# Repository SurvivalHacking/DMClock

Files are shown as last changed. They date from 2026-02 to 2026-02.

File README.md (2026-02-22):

# DMClock



IMG_5133_(00-00-00-00)

Background

## 📘 Descrizione / Description

Ispirato ai celebri display delle copertine dei singoli dei Depeche Mode, questo oggetto iconico diventa un vero orologio funzionante.
Segna ora e data, ma può anche rappresentare le annate storiche, proprio come nell’immaginario della band.
Un pezzo unico per veri fan.

Inspired by the famous displays on Depeche Mode's single covers, this iconic object becomes a real working clock.
It shows the time and date, but can also represent historical years, just like in the band's imagery.
A unique piece for true fans.

* Difficoltà/difficulties: Difficile / Hard
* Costo/cost: 30€
* Tempo / Time: 5 ore / 5 ours
* Attrezzature extra / extra devices: Stampante 3D / 3D printer

---
## 🎛️ Materiali / BOM

* Display C.C. 5161AS: https://s.click.aliexpress.com/e/_c3zw6A2p
* HT16K33 BackPack: https://s.click.aliexpress.com/e/_c2Q1blNZ
* ESP32C3: https://s.click.aliexpress.com/e/_DDST7Bj
* Button 6x6x12: https://s.click.aliexpress.com/e/_c4CBgRJJ
* Cavo 10 poli smaltato / 10 wire cable: https://s.click.aliexpress.com/e/_c3IRqse1
* PLA galaxy black: https://amzn.to/4rr7kVZ
* PLA gray glitter: https://amzn.to/4o0EEkQ

---

## 🎛️ Schema pratico di assemblaggio

Schema Pratico - Schematic

---
# 📝 Programmazione via WEB / WEB Programming

https://davidegatti.altervista.org/installaEsp32.php?progetto=DMClock 

---
## 🧾 Licenza

Questo progetto è distribuito con licenza
**Creative Commons – Attribuzione – Non Commerciale 4.0 Internazionale (CC BY-NC 4.0)**.

Puoi condividerlo e modificarlo liberamente, **citando l’autore**
(Davide Gatti / [survivalhacking](https://github.com/survivalhacking)) e **senza scopi commerciali**.

🔗 [https://creativecommons.org/licenses/by-nc/4.0/](https://creativecommons.org/licenses/by-nc/4.0/)

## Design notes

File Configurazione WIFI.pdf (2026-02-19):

# DM CLOCK

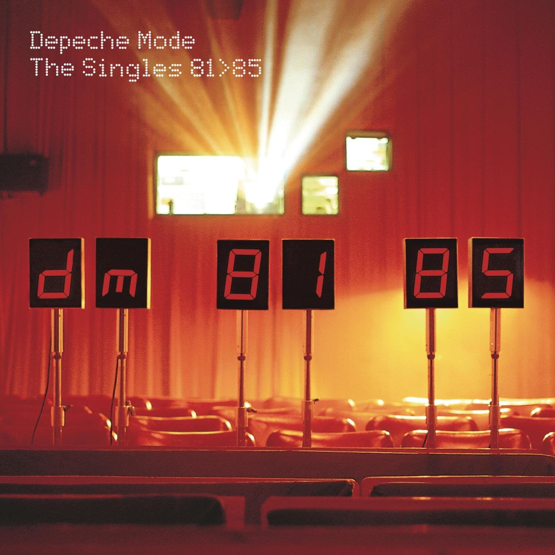
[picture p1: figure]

### Configurazione DM Clock

Questo orologio, prende l’ora da internet ed è quindi necessario collegarlo alla rete WIFI.

1) Alla prima accensione l’orologio mostra la scri=a WIFI che fa capire che è necessario collegarlo alla rete per proseguire.
2) UBlizzando un qualsiasi telefonino, cercare nella rete WIFI il disposiBvo DM-CLOCK e collegarsi ad esso
3) Se state usando un iPad o un iPhone, automaBcamente apparirà la schermata per la configurazione, diversamente sui disposiBvi Android sarà necessario collegarsi manualmente mediante un browser digitando il seguente indirizzo 192.168.4.1 oppure leggendo il seguente QR-CODE.

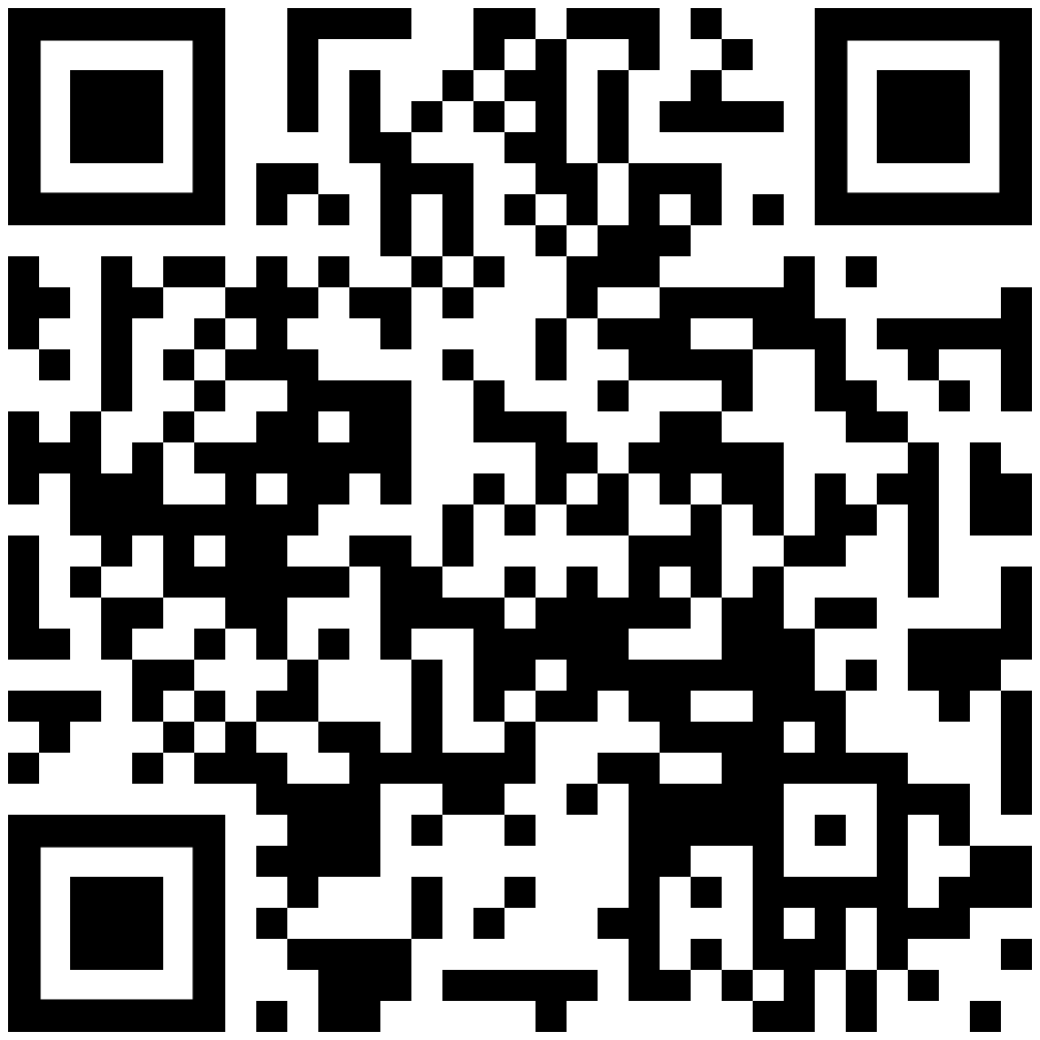
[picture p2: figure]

4) Una volta aperta la pagina di configurazione premere su ‘configure WiFi’

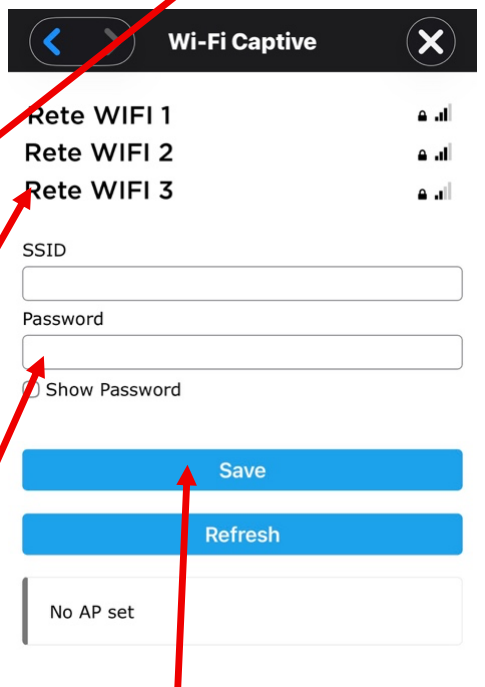
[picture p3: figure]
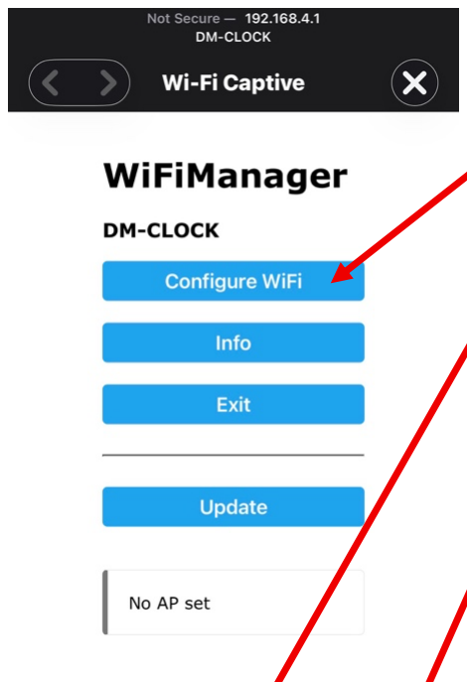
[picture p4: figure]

5) Selezionare la vostra rete WiFi e la password e premere ‘Save’
6) Se avete inserito le credenziali corre=amente, l’orologio si conne=erà automaBcamente e vi mostrerà l’indirizzo IP al quale è possibile raggiungerlo per eventuali configurazioni aggiunBve che sono opzionali, per cui se non necessario, saltare la parte di configurazione avanzata.

CONFIGURAZIONE AVANZATA

7) L’orologio da adesso in poi all’avvio mostrerà la scri=a “CONN” che significa che si sta conne=endo alla rete e a seguire vi mostrerà l’indirizzo IP assegnato. La visualizzazione avverrà in più passaggi IP= e poi 4 numeri in sequenza che una volta uniB comporranno l’indirizzo IP completo. Per esempio
IP=
192.
168.
1.
98.

Compongono l’indirizzo IP 192.168.1.98. Che se digitato sul proprio browser vi darà l’accesso alla pagina di configurazione estesa.

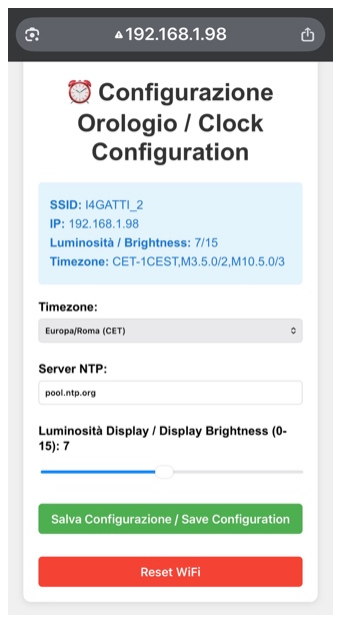
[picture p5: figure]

8) Da qui sarò possibile cambiare il Timezone, il server NTP, la luminosità ed eventualmente rese=are le impostazioni del WIFI che si possono comunque rese=are anche usando i due pulsanB presenB sull’orologio.

ISTRUZIONI OROLOGIO DM-CLOCK

L’orologio normalmente mostra l’ora che viene sincronizzata da internet e si regola automaBcamente anche l’ora legale.
Per interagire ci sono 2 pulsanB che consentono l’esecuzione di alcune impostazioni.

Pulsante di sinistra
Premendo il pulsante una prima volta, verrà mostrata la data per 5 secondi.
Premendo nuovamente il pulsante di sinistra viene mostrata la scri=a DM 81 85
Premendo nuovamente il pulsante di sinistra viene mostrata la scri=a 86 89 per 10 secondi Premendo nuovamente il pulsante di sinistra viene mostrata la scri=a 01 17 per 10 secondi
Premendo nuovamente il pulsante di sinistra viene mostrata la scri=a 01 24 per 10 secondi

Pulsante di destra
Premendo il pulsante si regola la luminosità. Ad ogni pressione si incrementa la luminosità che va da 0 a 15

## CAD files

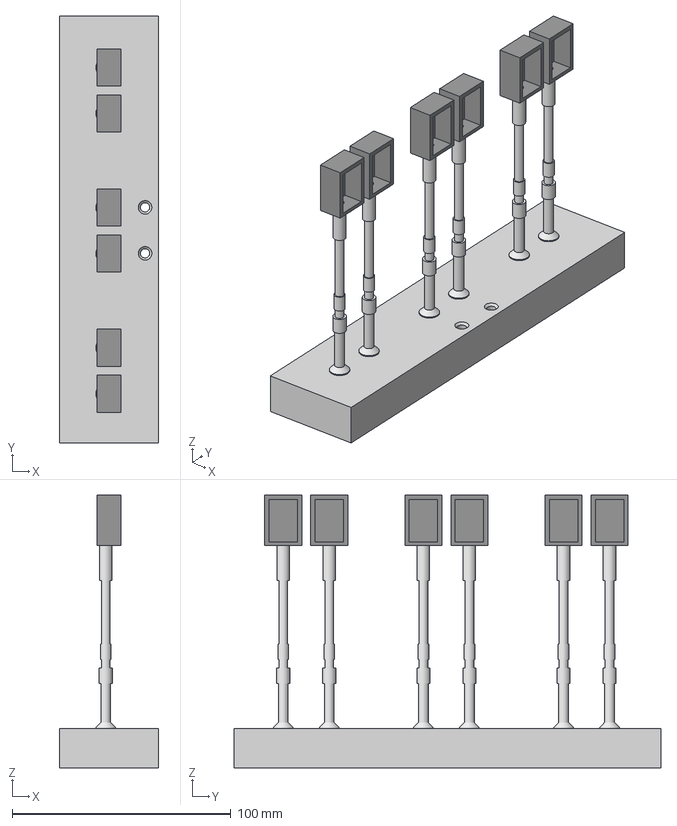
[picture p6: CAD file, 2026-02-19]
3D/DM Clock FULL.3mf
45.0 x 195.0 x 124.5 mm
Asta (1) (1)
Asta (2) (1) (1)
Asta (2) (1)
Asta (4) (1) (1)
Asta (4) (1)
Asta (6) (1)
BASE (1)
DISPLAY (1) (1)
DISPLAY (2) (1)
DISPLAY (3) (1)
DISPLAY (4) (1)
DISPLAY (5) (1)
DISPLAY (6)

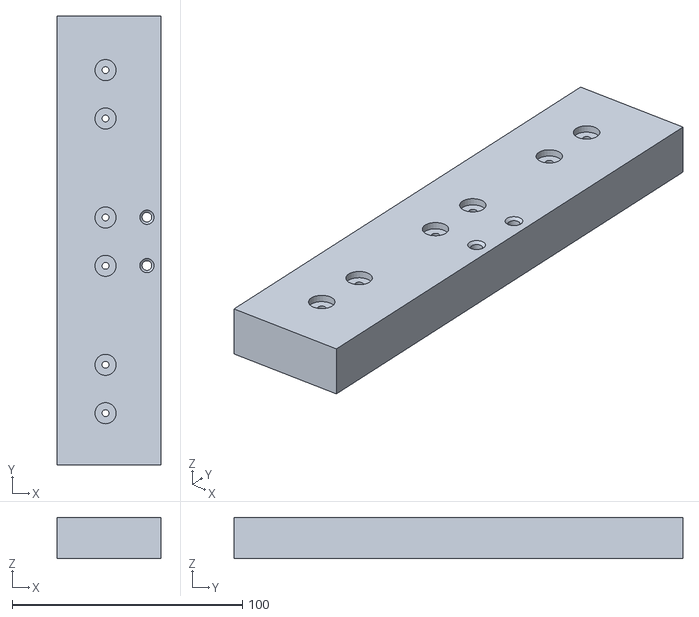
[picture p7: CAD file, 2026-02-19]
3D/BASE.stl
45.0 x 195.0 x 18.0

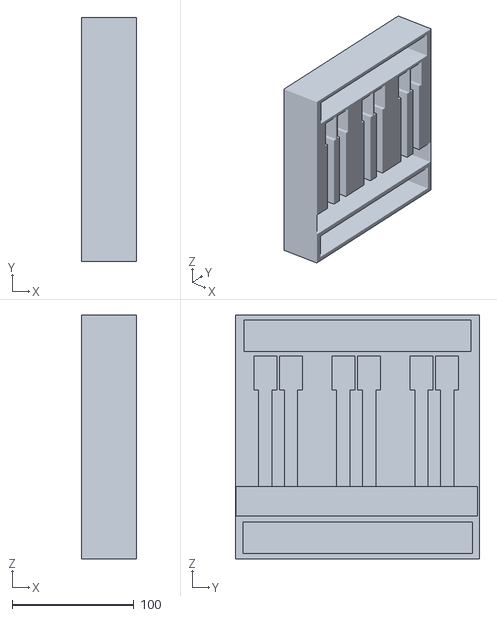
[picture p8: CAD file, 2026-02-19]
3D/Contenitore/bot.stl
45.0 x 200.0 x 200.0

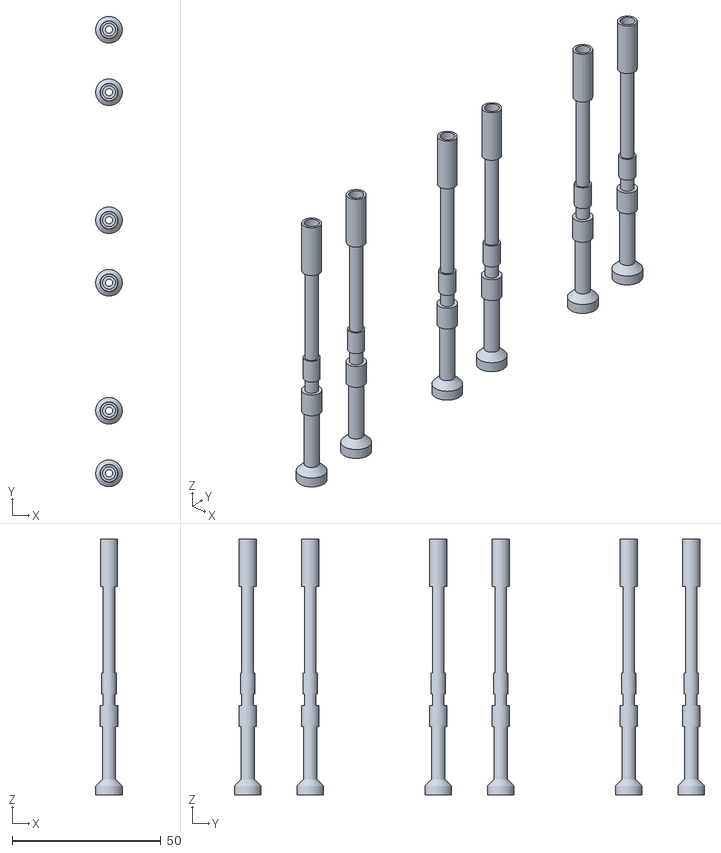
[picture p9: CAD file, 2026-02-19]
3D/ASTE.stl
8.99 x 158.0 x 86.0

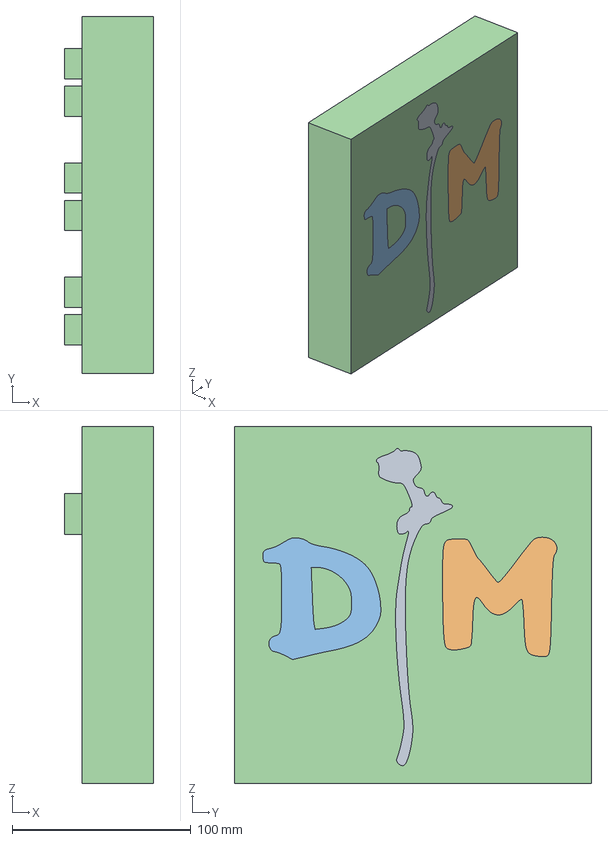
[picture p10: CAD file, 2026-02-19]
3D/Contenitore/TOP.3mf
50.0 x 200.0 x 200.0 mm
DM (1)
DM (2)
DM
TOP

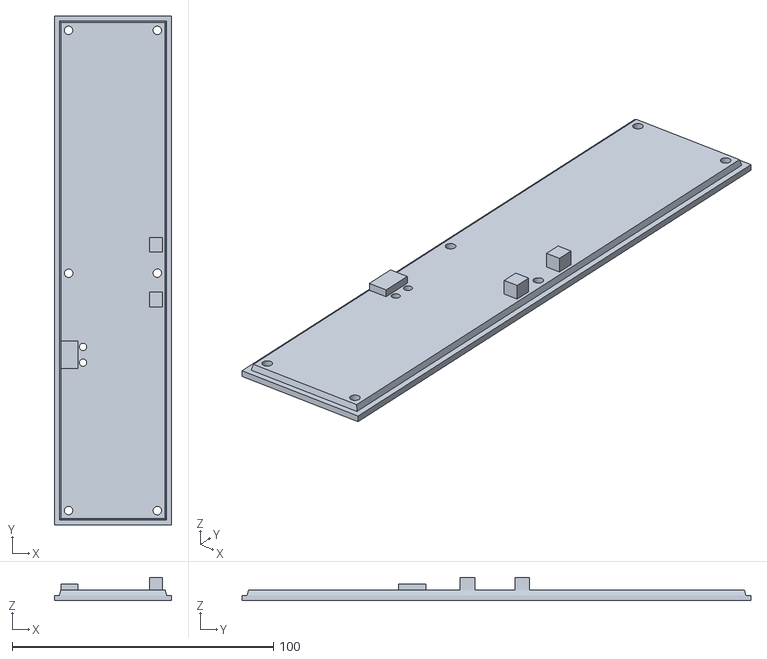
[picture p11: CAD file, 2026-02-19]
3D/Tappo.stl
45.0 x 195.0 x 8.81

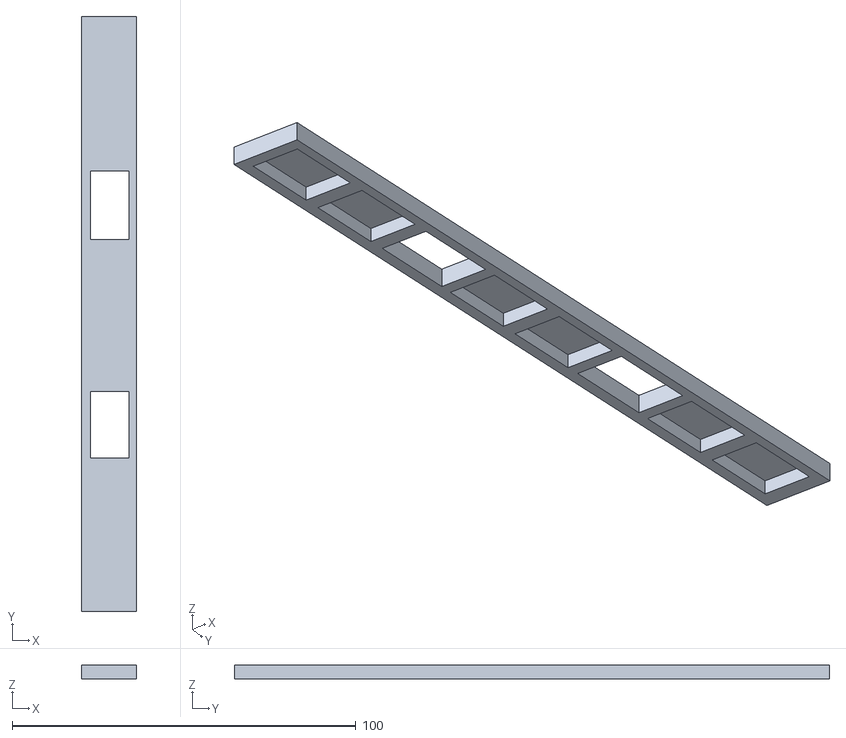
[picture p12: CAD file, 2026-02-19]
3D/DIMA.stl
16.0 x 173.0 x 4.00

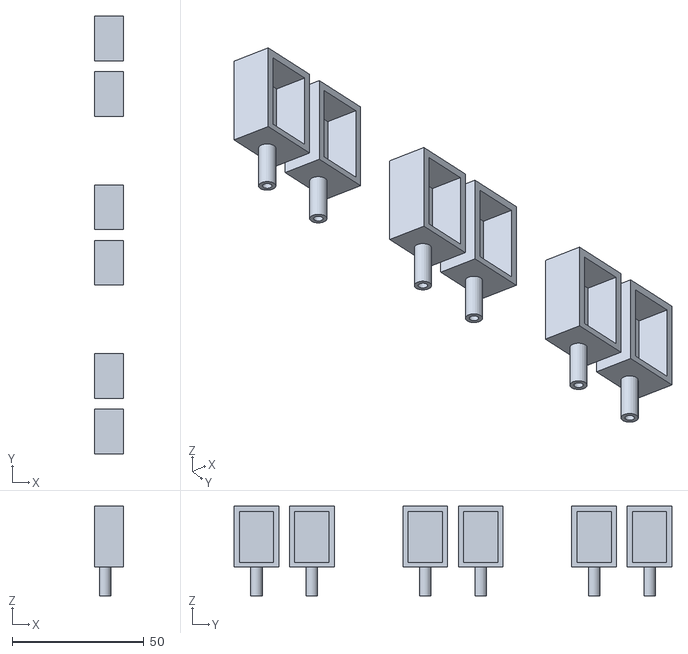
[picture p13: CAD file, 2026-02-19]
3D/DISPLAY.stl
11.0 x 166.0 x 34.0

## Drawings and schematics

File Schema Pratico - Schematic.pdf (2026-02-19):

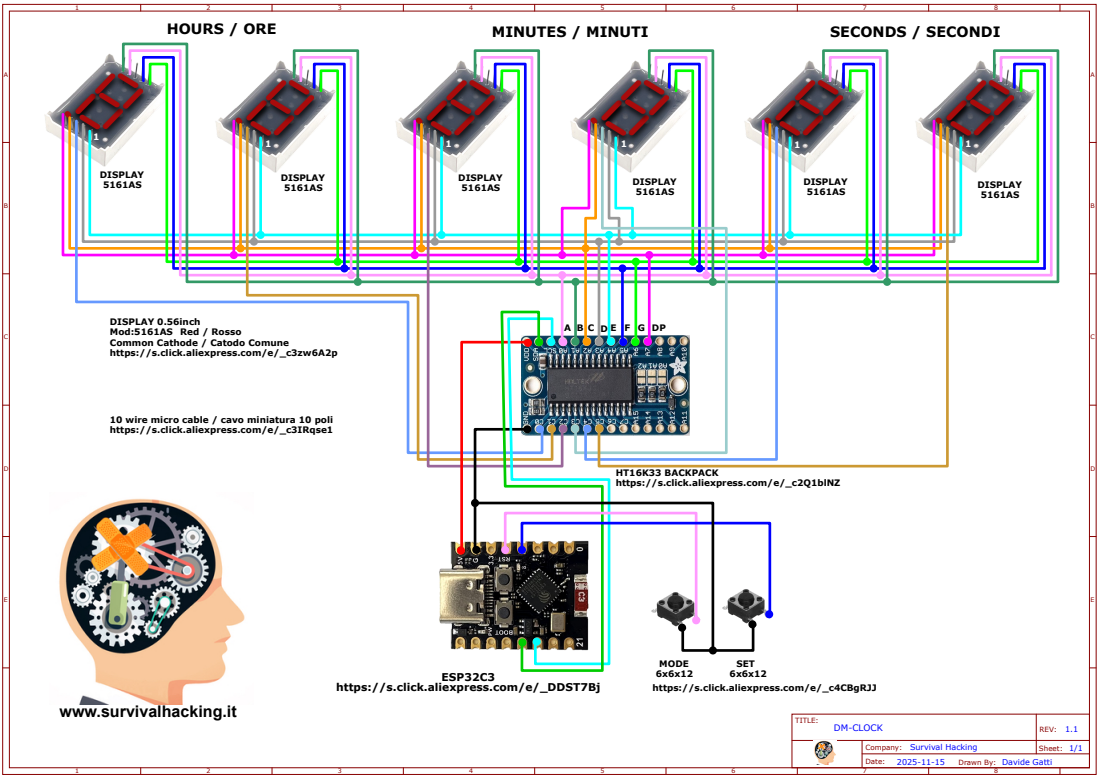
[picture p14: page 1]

DISPLAY 0.56inch
Mod:5161AS Red / Rosso
Common Cathode / Catodo Comune
https://s.click.aliexpress.com/e/_c3zw6A2p

10 wire micro cable / cavo miniatura 10 poli
https://s.click.aliexpress.com/e/_c3IRqse1

HT16K33 BACKPACK
https://s.click.aliexpress.com/e/_c2Q1blNZ

https://s.click.aliexpress.com/e/_DDST7Bj

TITLE: DM-CLOCK | REV: 1.1

Company: Survival Hacking | Sheet: 1/1

Drawn By: Davide Gatti

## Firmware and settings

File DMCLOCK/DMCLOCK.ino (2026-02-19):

// DM-CLOCK V1.0 16/11/25 by davide gatti - Survival hacking - www.survivalhacking.it
//
// Un orologio ispirato alle copertine dei Singles dei Depeche Mode. / A clock inspired by the covers of Depeche Mode's singles.
// 
// Per funzionare si deve collegare alla rete WIFI: / To operate, it must be connected to a Wi-Fi network:
// All'avvio si configura in access point, cercare nella rete WIFI il dispositivo DM-CLOCK e collegarsi. Se non appare automaticamente la pagina di configurazione andare con il browser all'indirizzo 192.168.1.4 e da li configurare la rete WIFI e il vosto fuso orario.
// When starting up, configure it as an access point, search for the DM-CLOCK device on the Wi-Fi network, and connect. If the configuration page does not appear automatically, go to 192.168.1.4 in your browser and configure the Wi-Fi network and your time zone from there.

// Funzioni: / Functions:
// 
// Tasto MODE: premuto una volta mostra la data e premuto ulteriori volte mostra il messaggio iconico dei titoli degli album tipo DM 81 89
// Tasto LUMA: consente di recolare la luminosità.
// 
// Tenendo premuto il tasto MODE durante l'accensione verranno cancellate le impostazioni WIFI
//
//
// MODE button: press once to display the date and press again to display the iconic message of album titles such as DM 81 89.
// LUMA button: allows you to adjust the brightness.
//
// Holding down the MODE button while turning on the device will clear the Wi-Fi settings.
//
//


#include <Wire.h>
#include <Adafruit_GFX.h>
#include <Adafruit_LEDBackpack.h>
#include <WiFi.h>
#include <WiFiManager.h>
#include <time.h>
#include <Preferences.h>
#include <WebServer.h>

// ========================================
// CONFIGURAZIONE HARDWARE / HARDWARE CONFIGURATION
// ========================================

// Pin I2C / I2C pins
const int SDA_PIN = 9;
const int SCL_PIN = 10;

// Display a 6 cifre / 6-digit display
Adafruit_LEDBackpack matrix = Adafruit_LEDBackpack();

// ========================================
// CONFIGURAZIONE NTP / NTP CONFIGURATION
// ========================================

// Server NTP / NTP server
const char* ntpServer = "pool.ntp.org";

// Timezone con ora legale automatica (formato POSIX) / Timezone with automatic DST (POSIX format)
String timezoneStr = "CET-1CEST,M3.5.0/2,M10.5.0/3";  // Roma/Italia / Rome/Italy

// ========================================
// PIN PULSANTI / BUTTON PINS
// ========================================

#define PIN_MODE 3      // Pulsante MODE / MODE button
#define PIN_FUNCTION 4  // Pulsante FUNCTION / FUNCTION button

// ========================================
// VARIABILI GLOBALI / GLOBAL VARIABLES
// ========================================

Preferences preferences;  // Memoria persistente / Persistent storage
WebServer server(80);     // Server web / Web server
int brightness = 7;       // Luminosità display (0-15) / Display brightness (0-15)
int displayMode = 0;      // Modalità display: 0=ora, 1=data, 2-4=messaggi / Display mode: 0=time, 1=date, 2-4=messages
unsigned long modeChangeTime = 0;  // Timestamp cambio modalità / Mode change timestamp
int animationStep = 0;    // Step animazione connessione / Connection animation step
unsigned long lastAnimationUpdate = 0;  // Ultimo aggiornamento animazione / Last animation update

// Variabili debouncing pulsanti / Button debouncing variables
unsigned long lastModePress = 0;
unsigned long lastFunctionPress = 0;
const unsigned long debounceDelay = 200;

// ========================================
// TABELLA CARATTERI 7 SEGMENTI / 7-SEGMENT CHARACTER TABLE
// ========================================

// Tabella conversione numeri 0-9 in formato 7 segmenti (PGFEDCBA)
// Conversion table for digits 0-9 to 7-segment format (PGFEDCBA)
static const uint8_t numbertable[] = {
  0b00111111, // 0
  0b00000110, // 1
  0b01011011, // 2
  0b01001111, // 3
  0b01100110, // 4
  0b01101101, // 5
  0b01111101, // 6
  0b00000111, // 7
  0b01111111, // 8
  0b01101111  // 9
};

// ========================================
// SETUP
// ========================================

void setup() {
  Serial.begin(115200);
  
  // Inizializza I2C / Initialize I2C
  Wire.begin(SDA_PIN, SCL_PIN);
  
  // Inizializza display / Initialize display
  matrix.begin(0x70);
  
  // Inizializza memoria persistente / Initialize persistent storage
  preferences.begin("clock", false);
  brightness = preferences.getInt("brightness", 7);
  matrix.setBrightness(brightness);
  
  // Configura pulsanti con pull-up / Configure buttons with pull-up
  pinMode(PIN_MODE, INPUT_PULLUP);
  pinMode(PIN_FUNCTION, INPUT_PULLUP);
  
  // Controlla se MODE è premuto all'avvio per reset WiFi / Check if MODE is pressed at startup for WiFi reset
  if (digitalRead(PIN_MODE) == LOW) {
    Serial.println("Reset WiFi richiesto! / WiFi reset requested!");
    showResetMessage();
    delay(2000);
    
    WiFiManager wm;
    wm.resetSettings();
    preferences.clear();
    
    // Mostra "OK" sul display / Show "OK" on display
    matrix.clear();
    matrix.displaybuffer[0] = 0b00111111; // O
    matrix.displaybuffer[1] = 0b01010111; // K
    matrix.writeDisplay();
    delay(2000);
    
    ESP.restart();
  }
  
  // Mostra "CONN" durante connessione / Show "CONN" during connection
  showConnMessage();  
  
  // Configura WiFiManager / Configure WiFiManager
  WiFiManager wm;
  
  // Callback per salvataggio configurazione / Callback for configuration save
  wm.setSaveConfigCallback([]() {
    Serial.println("Configurazione salvata, riavvio... / Configuration saved, restarting...");
  });
  
  // Callback per modalità AP / Callback for AP mode
  wm.setAPCallback([](WiFiManager *myWiFiManager) {
    Serial.println("Modalità AP attiva / AP mode active");
    showWiFiMessage();
  });
  
  // Timeout portale configurazione / Configuration portal timeout
  wm.setConfigPortalTimeout(180); // 3 minuti / 3 minutes
  
  // Connessione WiFi con portale captive (senza password) / WiFi connection with captive portal (no password)
  bool res = wm.autoConnect("DM-CLOCK");
  
  if (!res) {
    Serial.println("Connessione fallita! / Connection failed!");
    showWiFiMessage();
    delay(3000);
    ESP.restart();
  }
  
  // Verifica connessione effettiva / Verify actual connection
  Serial.println("WiFi configurato, controllo connessione... / WiFi configured, checking connection...");
  
  int retries = 0;
  while (WiFi.status() != WL_CONNECTED && retries < 20) {
    animateConnecting();
    delay(500);
    retries++;
  }
  
  if (WiFi.status() != WL_CONNECTED) {
    Serial.println("Connessione WiFi fallita dopo configurazione, riavvio... / WiFi connection failed after configuration, restarting...");
    delay(1000);
    ESP.restart();
  }
  
  Serial.println("\nWiFi connesso! / WiFi connected!");
  Serial.print("IP: ");
  Serial.println(WiFi.localIP());
  
  // Mostra indirizzo IP sul display / Show IP address on display
  showIPAddress();
  
  // Carica timezone dalle preferenze / Load timezone from preferences
  timezoneStr = preferences.getString("timezone", "CET-1CEST,M3.5.0/2,M10.5.0/3");
  
  // Configura NTP con timezone (ora legale automatica) / Configure NTP with timezone (automatic DST)
  configTzTime(timezoneStr.c_str(), ntpServer);
  
  // Attendi sincronizzazione NTP / Wait for NTP synchronization
  struct tm timeinfo;
  int attempts = 0;
  while (!getLocalTime(&timeinfo) && attempts < 30) {
    Serial.println("Attendo sincronizzazione NTP... / Waiting for NTP sync...");
    animateConnecting();
    delay(1000);
    attempts++;
  }
  
  // Avvia server web / Start web server
  setupWebServer();
  server.begin();
  
  Serial.println("Orologio avviato! / Clock started!");
}

// ========================================
// LOOP PRINCIPALE / MAIN LOOP
// ========================================

void loop() {
  // Gestione richieste web / Handle web requests
  server.handleClient();
  
  // Gestione pulsante MODE / Handle MODE button
  if (digitalRead(PIN_MODE) == LOW && (millis() - lastModePress > debounceDelay)) {
    lastModePress = millis();
    cycleDisplayMode();
  }
  
  // Gestione pulsante FUNCTION (luminosità) / Handle FUNCTION button (brightness)
  if (digitalRead(PIN_FUNCTION) == LOW && (millis() - lastFunctionPress > debounceDelay)) {
    lastFunctionPress = millis();
    adjustBrightness();
  }
  
  // Timeout automatico per modalità diverse dall'ora / Automatic timeout for non-time modes
  unsigned long timeout = (displayMode == 1) ? 5000 : 10000; // 5 sec per data, 10 sec per messaggi / 5 sec for date, 10 sec for messages
  if (displayMode != 0 && (millis() - modeChangeTime > timeout)) {
    displayMode = 0; // Torna all'ora / Return to time
  }
  
  // Visualizzazione in base alla modalità / Display based on mode
  switch (displayMode) {
    case 0:
      displayTime();      // Ora / Time
      break;
    case 1:
      displayDate();      // Data / Date
      break;
    case 2:
      displayMessage1();  // DM8185
      break;
    case 3:
      displayMessage2();  // DM8698
      break;
    case 4:
      displayMessage3();  // DM0117
      break;
    case 5:
      displayMessage4();  // DM0124
      break;
  }
  
  delay(100);
}

// ========================================
// FUNZIONI MESSAGGI DISPLAY / DISPLAY MESSAGE FUNCTIONS
// ========================================

//   A
// F   B
//   G
// E   C
//   D   P
// Mappa segmenti display 7-seg / 7-segment display map

// Mostra "WIFI" sul display / Show "WIFI" on display
void showWiFiMessage() {
  matrix.clear();
  matrix.displaybuffer[0] = 0b01111110; // W
  matrix.displaybuffer[1] = 0b00000110; // I
  matrix.displaybuffer[2] = 0b01110001; // F
  matrix.displaybuffer[3] = 0b00000110; // I
  matrix.writeDisplay();
}

// Mostra "CONN" (connessione) sul display / Show "CONN" (connecting) on display
void showConnMessage() {
  matrix.clear();
  matrix.displaybuffer[0] = 0b00111001; // C
  matrix.displaybuffer[1] = 0b00111111; // O
  matrix.displaybuffer[2] = 0b01010100; // N
  matrix.displaybuffer[3] = 0b01010100; // N
  matrix.writeDisplay();
}

// Mostra "RESET" (reset) sul display / Show "RESET" (reset) on display
void showResetMessage() {
  matrix.clear();
  matrix.displaybuffer[0] = 0b01010000; // R
  matrix.displaybuffer[1] = 0b01111001; // E
  matrix.displaybuffer[2] = 0b01101101; // S
  matrix.displaybuffer[3] = 0b01111001; // E
  matrix.displaybuffer[4] = 0b01111000; // T
  matrix.writeDisplay();
}

// Mostra indirizzo IP completo segmentato con punti / Show complete IP address segmented with dots
void showIPAddress() {
  IPAddress ip = WiFi.localIP();
  
  // Mostra "IP=" / Show "IP="
  matrix.clear();
  matrix.displaybuffer[0] = 0b00000110; // I
  matrix.displaybuffer[1] = 0b01110011; // P
  matrix.displaybuffer[2] = 0b00001001; // =
  matrix.writeDisplay();
  delay(1000);
  
  // Mostra primo ottetto con punto (es. 192.) / Show first octet with dot (e.g. 192.)
  displayNumberWithDot(ip[0], true);
  delay(1000);
  
  // Mostra secondo ottetto con punto (es. 168.) / Show second octet with dot (e.g. 168.)
  displayNumberWithDot(ip[1], true);
  delay(1000);
  
  // Mostra terzo ottetto con punto (es. 1.) / Show third octet with dot (e.g. 1.)
  displayNumberWithDot(ip[2], true);
  delay(1000);
  
  // Mostra quarto ottetto senza punto (es. 98) / Show fourth octet without dot (e.g. 98)
  displayNumberWithDot(ip[3], false);
  delay(1000);
  matrix.clear();
  delay(500);
}

// Funzione helper per visualizzare un numero allineato a destra con punto opzionale / Helper function to display right-aligned number with optional dot
void displayNumberWithDot(int num, bool showDot) {
  matrix.clear();
  
  if (num >= 100) {
    // 3 cifre / 3 digits
    matrix.displaybuffer[3] = numbertable[num / 100];
    matrix.displaybuffer[4] = numbertable[(num / 10) % 10];
    matrix.displaybuffer[5] = numbertable[num % 10];
    if (showDot) {
      matrix.displaybuffer[5] |= 0b10000000; // Aggiungi punto decimale / Add decimal point
    }
  } else if (num >= 10) {
    // 2 cifre / 2 digits
    matrix.displaybuffer[4] = numbertable[num / 10];
    matrix.displaybuffer[5] = numbertable[num % 10];
    if (showDot) {
      matrix.displaybuffer[5] |= 0b10000000; // Aggiungi punto decimale / Add decimal point
    }
  } else {
    // 1 cifra / 1 digit
    matrix.displaybuffer[5] = numbertable[num];
    if (showDot) {
      matrix.displaybuffer[5] |= 0b10000000; // Aggiungi punto decimale / Add decimal point
    }
  }
  
  matrix.writeDisplay();
}



// Animazione durante connessione WiFi / Animation during WiFi connection
void animateConnecting() {
  matrix.clear();
  
  // Anima punti centrali / Animate center dots
  if (animationStep == 0) {
    matrix.displaybuffer[2] = 0b10000000;
    matrix.displaybuffer[3] = 0b10000000;
  } else {
    matrix.displaybuffer[2] = 0b00001001;
    matrix.displaybuffer[3] = 0b00001001;
  }
  
  matrix.writeDisplay();
  animationStep = (animationStep + 1) % 2;
}

// ========================================
// FUNZIONI VISUALIZZAZIONE / DISPLAY FUNCTIONS
// ========================================

// Visualizza ora in formato HH:MM:SS / Display time in HH:MM:SS format
void displayTime() {
  struct tm timeinfo;
  if (!getLocalTime(&timeinfo)) {
    return;
  }
  
  int hours = timeinfo.tm_hour;
  int minutes = timeinfo.tm_min;
  int seconds = timeinfo.tm_sec;
  
  matrix.clear();
  
  // Visualizza HH:MM:SS sui 6 digit / Display HH:MM:SS on 6 digits
  matrix.displaybuffer[0] = numbertable[hours / 10];
  matrix.displaybuffer[1] = numbertable[hours % 10];
  matrix.displaybuffer[2] = numbertable[minutes / 10];
  matrix.displaybuffer[3] = numbertable[minutes % 10];
  matrix.displaybuffer[4] = numbertable[seconds / 10];
  matrix.displaybuffer[5] = numbertable[seconds % 10];
  
  matrix.writeDisplay();
}

// Visualizza data in formato GG:MM:AA / Display date in DD:MM:YY format
void displayDate() {
  struct tm timeinfo;
  if (!getLocalTime(&timeinfo)) {
    return;
  }
  
  int day = timeinfo.tm_mday;
  int month = timeinfo.tm_mon + 1;
  int year = (timeinfo.tm_year + 1900) % 100;
  
  matrix.clear();
  
  // Visualizza GG:MM:AA / Display DD:MM:YY
  matrix.displaybuffer[0] = numbertable[day / 10];
  matrix.displaybuffer[1] = numbertable[day % 10];
  matrix.displaybuffer[2] = numbertable[month / 10];
  matrix.displaybuffer[3] = numbertable[month % 10];
  matrix.displaybuffer[4] = numbertable[year / 10];
  matrix.displaybuffer[5] = numbertable[year % 10];
  
  matrix.writeDisplay();
  delay(100);
}

// Cicla tra le modalità di visualizzazione / Cycle through display modes
void cycleDisplayMode() {
  displayMode = (displayMode + 1) % 6; // Cicla da 0 a 5 / Cycle from 0 to 5
  modeChangeTime = millis();
}

// Visualizza messaggio "DM8185" / Display message "DM8185"
void displayMessage1() {
  matrix.clear();
  matrix.displaybuffer[0] = 0b01011110; // D
  matrix.displaybuffer[1] = 0b11010100; // M
  matrix.displaybuffer[2] = numbertable[8];
  matrix.displaybuffer[3] = numbertable[1];
  matrix.displaybuffer[4] = numbertable[8];
  matrix.displaybuffer[5] = numbertable[5];
  matrix.writeDisplay();
  delay(100);
}

// Visualizza messaggio "DM8698" / Display message "DM8698"
void displayMessage2() {
  matrix.clear();
  matrix.displaybuffer[0] = 0b01011110; // D
  matrix.displaybuffer[1] = 0b11010100; // M
  matrix.displaybuffer[2] = numbertable[8];
  matrix.displaybuffer[3] = numbertable[6];
  matrix.displaybuffer[4] = numbertable[9];
  matrix.displaybuffer[5] = numbertable[8];
  matrix.writeDisplay();
  delay(100);
}

// Visualizza messaggio "DM0117" / Display message "DM0117"
void displayMessage3() {
  matrix.clear();
  matrix.displaybuffer[0] = 0b01011110; // D
  matrix.displaybuffer[1] = 0b11010100; // M
  matrix.displaybuffer[2] = numbertable[0];
  matrix.displaybuffer[3] = numbertable[1];
  matrix.displaybuffer[4] = numbertable[1];
  matrix.displaybuffer[5] = numbertable[7];
  matrix.writeDisplay();
  delay(100);
}

// Visualizza messaggio "DM0124" / Display message "DM0124"
void displayMessage4() {
  matrix.clear();
  matrix.displaybuffer[0] = 0b01011110; // D
  matrix.displaybuffer[1] = 0b11010100; // M
  matrix.displaybuffer[2] = numbertable[0];
  matrix.displaybuffer[3] = numbertable[1];
  matrix.displaybuffer[4] = numbertable[2];
  matrix.displaybuffer[5] = numbertable[4];
  matrix.writeDisplay();
  delay(100);
}


// ========================================
// FUNZIONE REGOLAZIONE LUMINOSITÀ / BRIGHTNESS ADJUSTMENT FUNCTION
// ========================================

// Regola luminosità display (0-15) / Adjust display brightness (0-15)
void adjustBrightness() {
  brightness = (brightness + 1) % 16;
  matrix.setBrightness(brightness);
  preferences.putInt("brightness", brightness);
  
  // Mostra "LUM" + valore luminosità / Show "LUM" + brightness value
  matrix.clear();
  matrix.displaybuffer[0] = 0b00111000; // L
  matrix.displaybuffer[1] = 0b00111110; // U
  matrix.displaybuffer[2] = 0b11010100; // M
  
  // Visualizza valore allineato a destra / Display value right-aligned
  if (brightness >= 10) {
    matrix.displaybuffer[4] = numbertable[1]; // 1
    matrix.displaybuffer[5] = numbertable[brightness - 10];
  } else {
    matrix.displaybuffer[5] = numbertable[brightness];
  }
  
  matrix.writeDisplay();
  delay(500);
}

// ========================================
// SERVER WEB / WEB SERVER
// ========================================
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

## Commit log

2026-02-19 Enhance README with project details and resources
    Added detailed project description, materials list, assembly diagram, and licensing information.
2026-02-19 £D Printer Files
    [ASTE.stl, BASE.stl, DIMA.stl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]
2026-02-19 Schema Pratico / Practical Schematic
2026-02-19 Arduino Code
2026-02-19 Remove obsolete components from BOM section
    Removed links for RGB matrix, Arduino Nano, DS3231, and buttons.
2026-02-19 Schema Pratico / Schematic
